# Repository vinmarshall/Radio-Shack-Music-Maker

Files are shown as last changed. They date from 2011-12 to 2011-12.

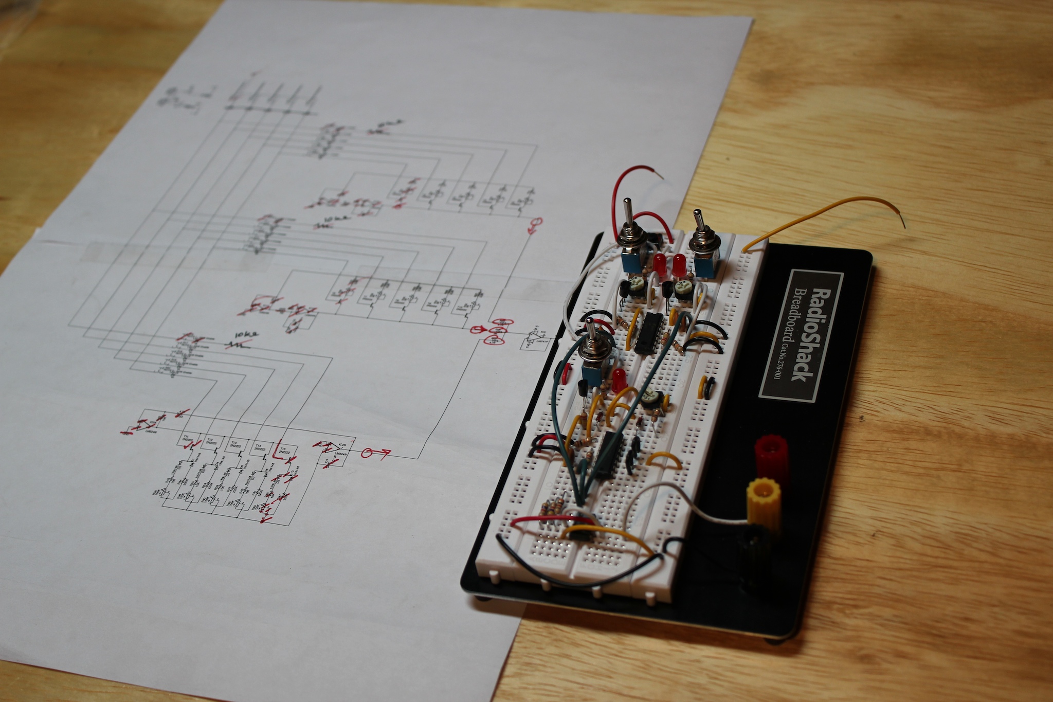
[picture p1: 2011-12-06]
images/prototype_001.jpg

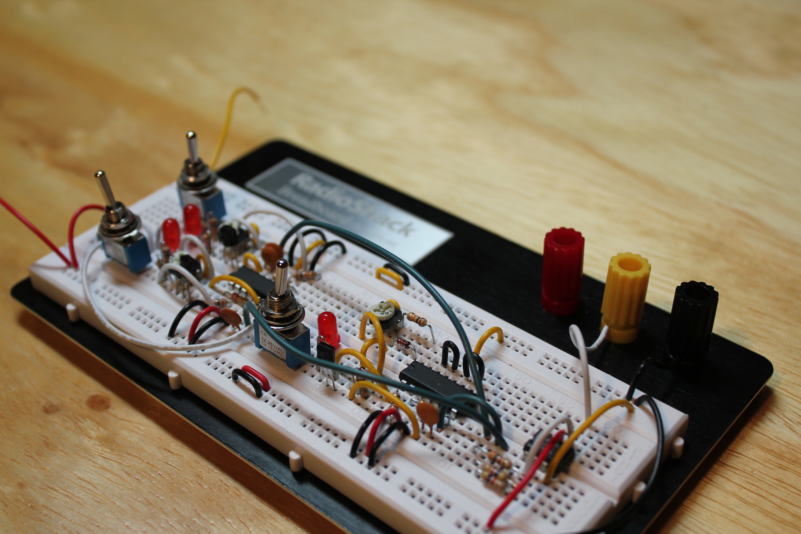
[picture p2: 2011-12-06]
images/prototype_003.jpg

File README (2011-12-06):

These files are the plans for the "Radio Shack Music Maker" in my post on PopSci:

http://www.popsci.com/diy/article/2011-11/sponsored-post-radioshack-music-maker-diy-project

./CAD The Alibre 3D model for the enclosure.

./PCB The Express PCB files - schematic and board layout.

./images Just what you'd expect.

./parts Information for sourcing parts.

./schematic The schematic.

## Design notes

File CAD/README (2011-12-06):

These files make up the 3-D model of the Music Maker.  They were made with 
Alibre CAD.  Get a copy of the software for yourself if you'd like to 
customize this enclosure or design your own.  http://www.alibre.com.

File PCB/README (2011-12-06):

These files are the schematic and PCB layout for the Music Maker.  This 
was made with the software from http://www.expresspcb.com.

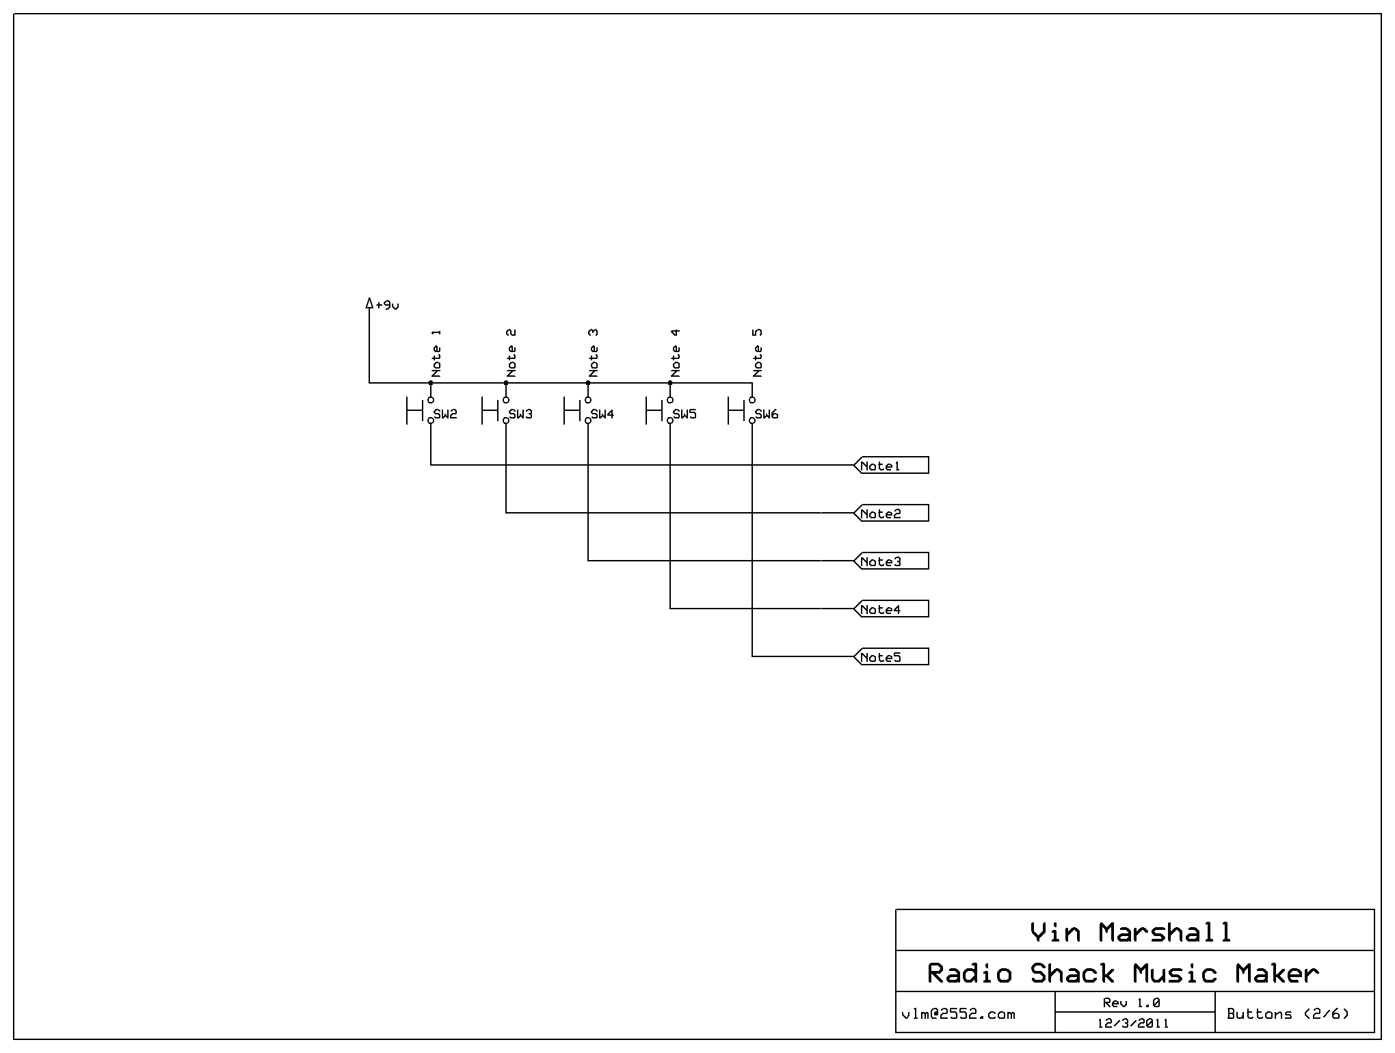
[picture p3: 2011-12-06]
schematic/2_buttons.bmp

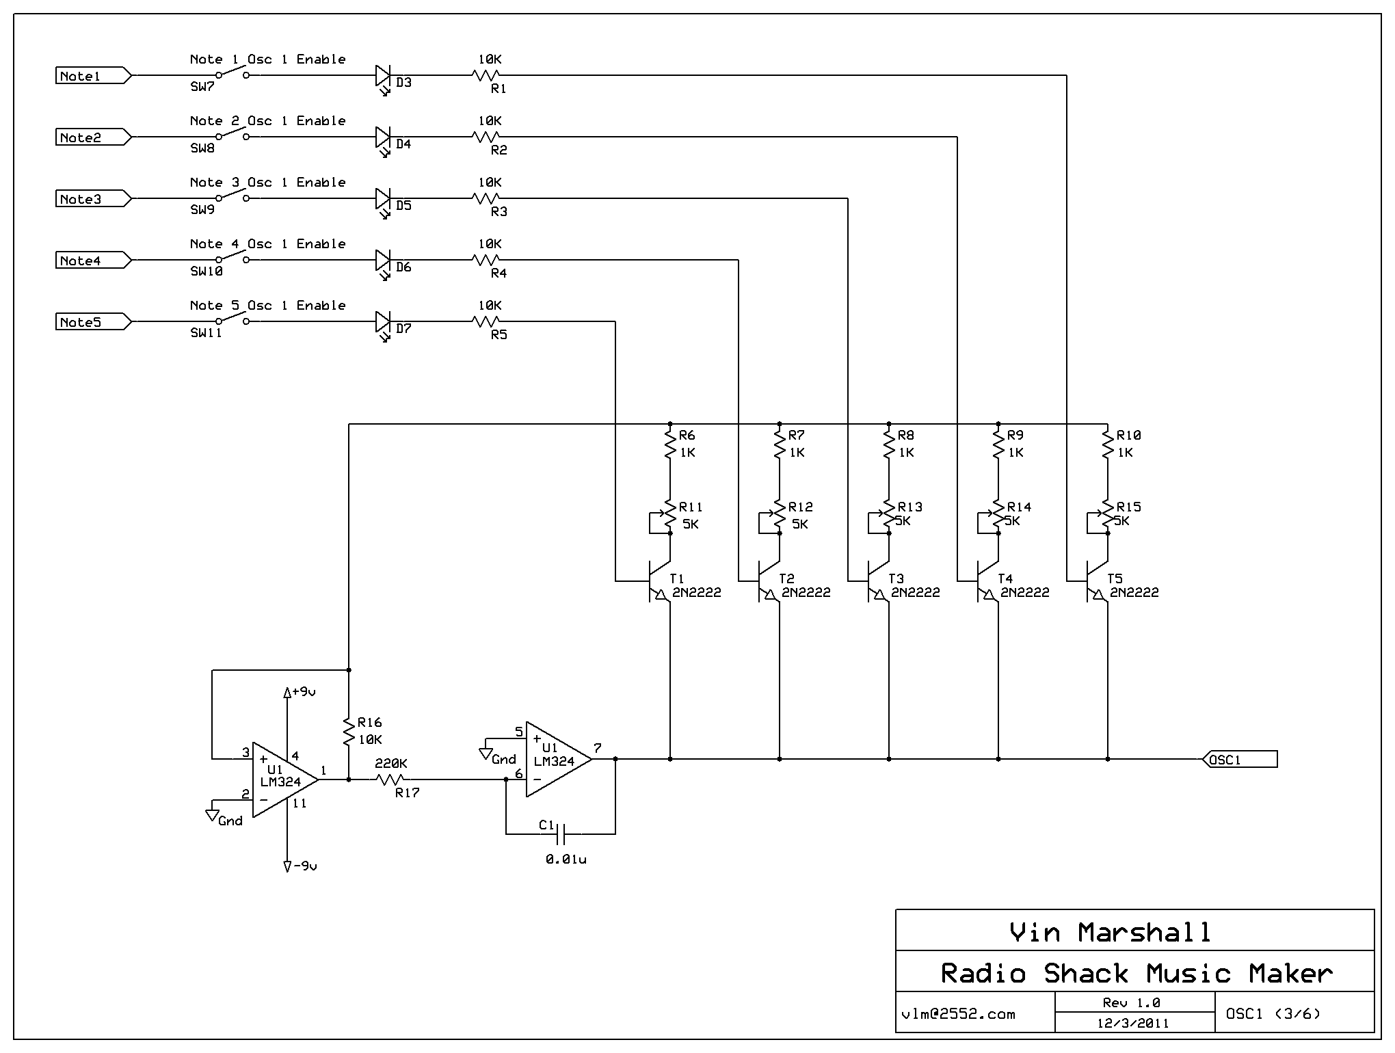
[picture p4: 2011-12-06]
schematic/3_oscillator_1.bmp

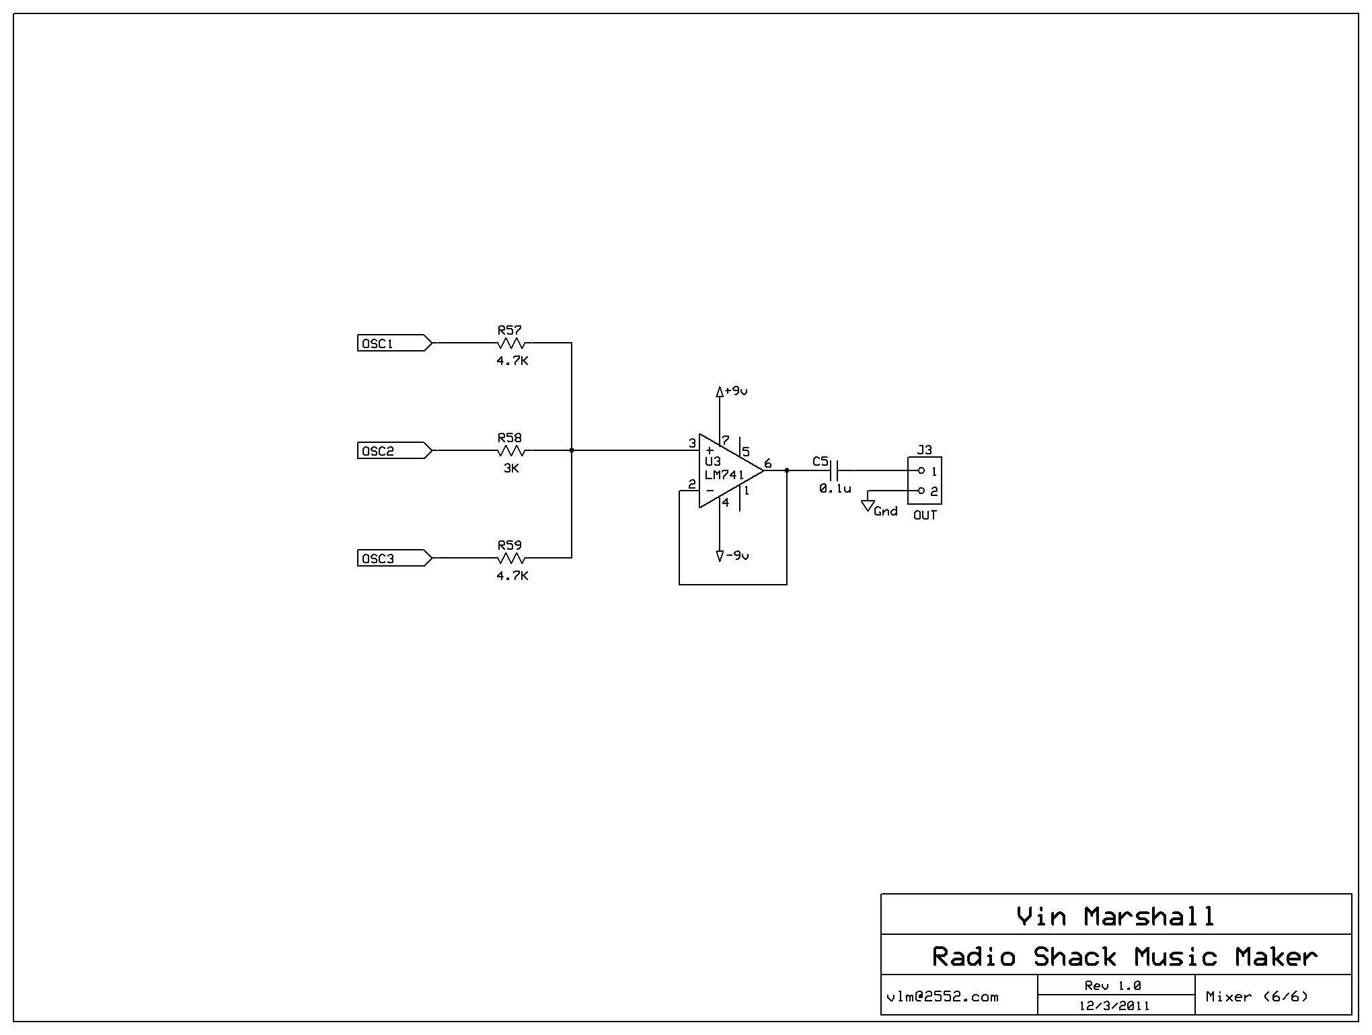
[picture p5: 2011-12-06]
schematic/6_mixer.bmp

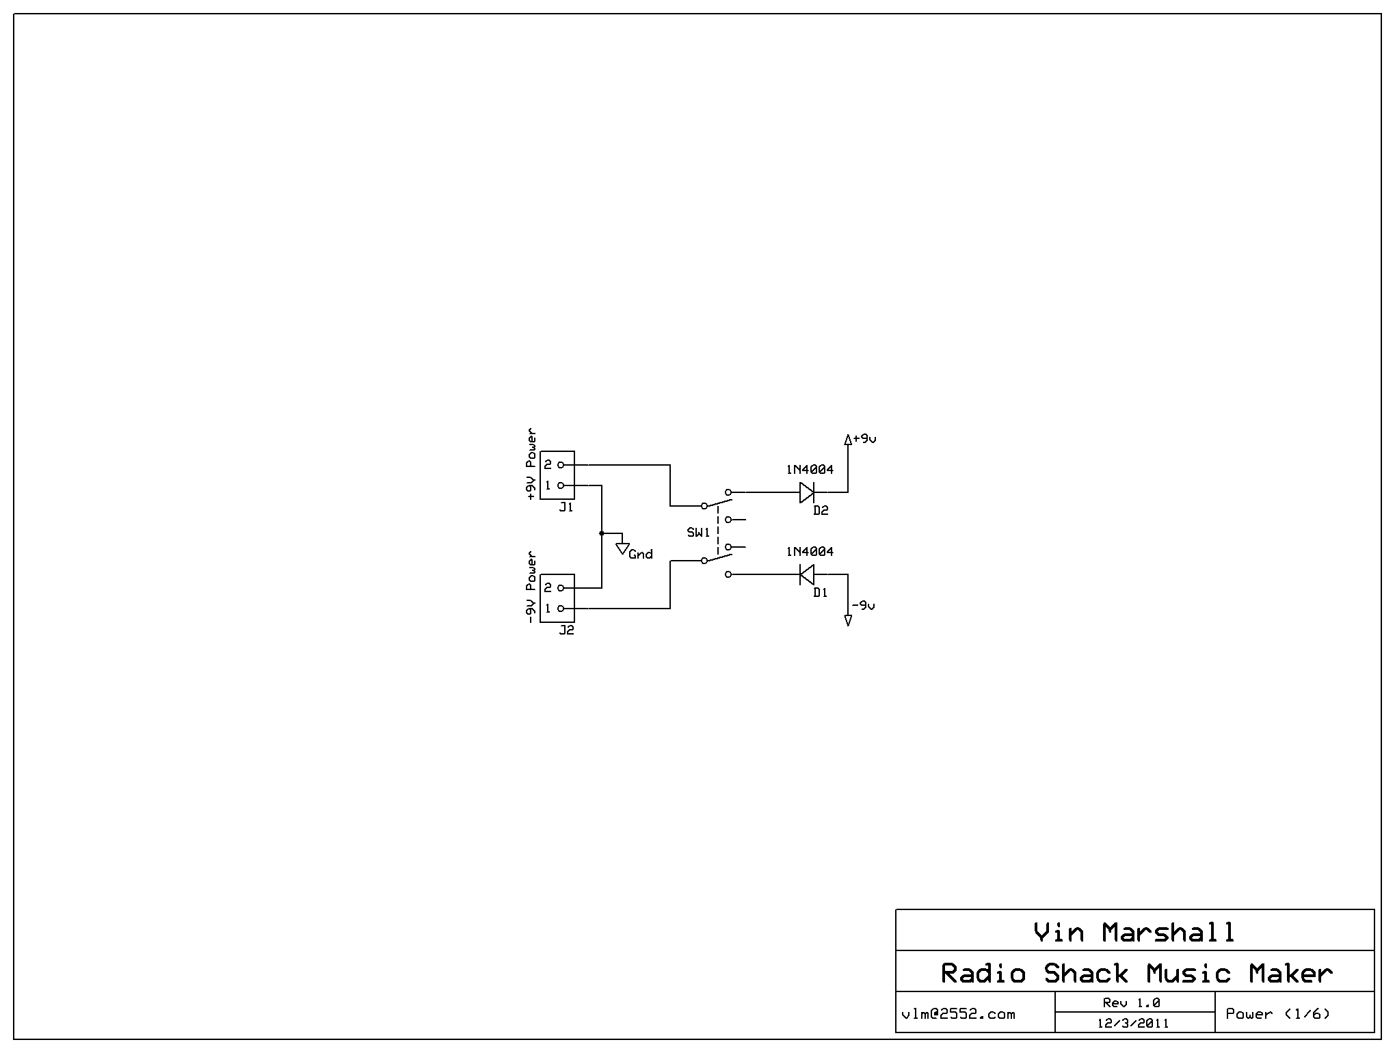
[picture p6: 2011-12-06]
schematic/1_power.bmp

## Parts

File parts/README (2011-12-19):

PCB:

The PCB can be sourced from ExpressPCB.  

The "ProtoPro" service gives you a 2 sided board with soldermask and 
silkscreening.  4 boards will cost just under $200.  

The "Standard" service gives you a perfectly functional 2 sided board with no 
soldermasks or silkscreening.  2 boards will cost about $100.

If I get sufficient interest, I'll make boards available for $40 each.

Instructions: 

- Download their software from http://www.expresspcb.com/ if you don't already 
have it.
- Open the ./PCB/music_maker.pcb file
- From the 'Layout' menu, select "Compute Board Cost" to see your options
  and then "Order Boards via the Internet" to order.

ENCLOSURE:

The front and back panels of the acrylic enclosure can be sourced from Pololu. 
It should cost around $40.

Instructions:

- Go to http://www.pololu.com/catalog/product/749 and click "Request a Quote"
- Upload the ./parts/music_maker_panels.dxf file, fill in a quantity and
  any special instructions, select a material, and wait for them to email you 
  a quote.  You can place the order at that point.

PARTS: 

I'm still working on the parts lists.

The electronics are listed in the Radio_Shack_BOM.pdf file. 

Source the standoffs and hardware from your favorite vendor.
 - 4x 2" x 0.25" OD Round standoffs, female-female, 8-32
 - 4x 3/8" x 0.25" OD Hex standoffs, female-male, 6-32
 - 4x 6-32 machine screws
 - 4x 6-32 nuts
 - 8x 8-32 machine screws
 - 2x 4-40 machine screws
 - 2x 4-40 nuts

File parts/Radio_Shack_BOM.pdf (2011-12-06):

Radio Shack Music Maker
Parts List

Push Button Switches – 5x p/n 275-609
SPST Mini Toggle Switches – 15x p/n 275-634
5K Potentiometers (cut shaft to length) – 10x p/n 271-1714 100K Potentiometers (cut shaft to length) – 5x p/n 271-092 Knobs – 4x p/n 274-415
DPDT Mini Toggle Switch – 1x p/n 275-636
1/4” Audio Jack – 1x p/n 274-252

9V Batteries – 2x p/n 23-853
9V Battery Holders – 1x p/n 270-326
9V Battery Clips – 1x p/n 270-324

1N4001 Rectifier Diodes – 1x p/n 276-1101 1N4148 Signal Diodes – 1x p/n 276-1122 Resistor Assortment – 1x p/n 271-312
LED Assortment – 2x p/n 276-1622
LM324 Quad Op Amp – 2x p/n 276-1711 LM741 Op Amp – 1x p/n 276-007
2N2222 NPN Transistors – 3x p/n 276-1617 0.01uF Capacitors – 2x p/n 272-1065 0.1uF Capacitor – 1x p/n 272-1069

Wire Assortment – p/n 278-1224

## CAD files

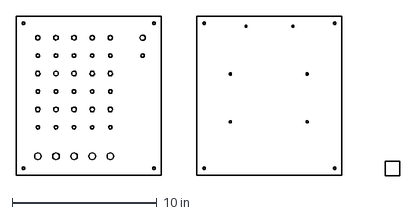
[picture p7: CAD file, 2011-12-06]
parts/music_maker_panels.dxf
26.5 x 11.0 in

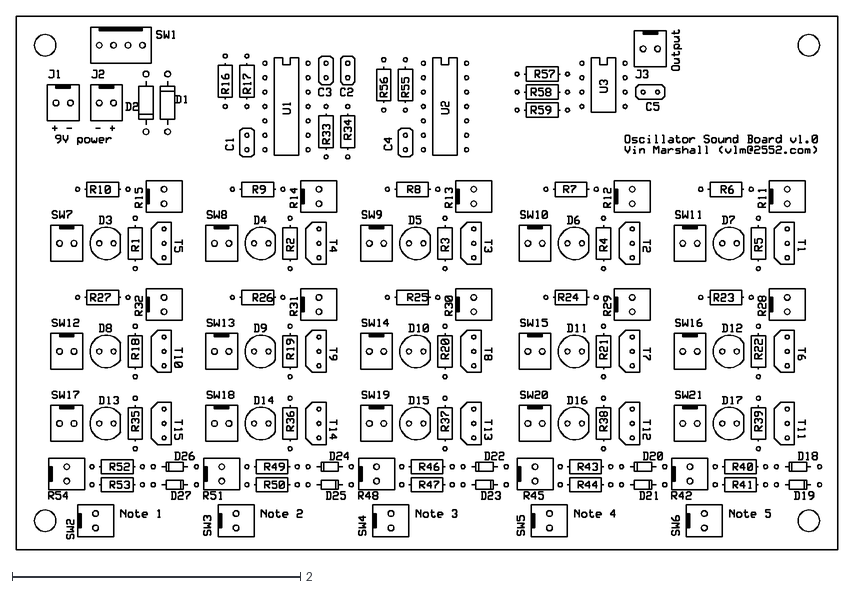
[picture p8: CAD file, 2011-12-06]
PCB/music_maker_pcb.dxf
5.70 x 3.70

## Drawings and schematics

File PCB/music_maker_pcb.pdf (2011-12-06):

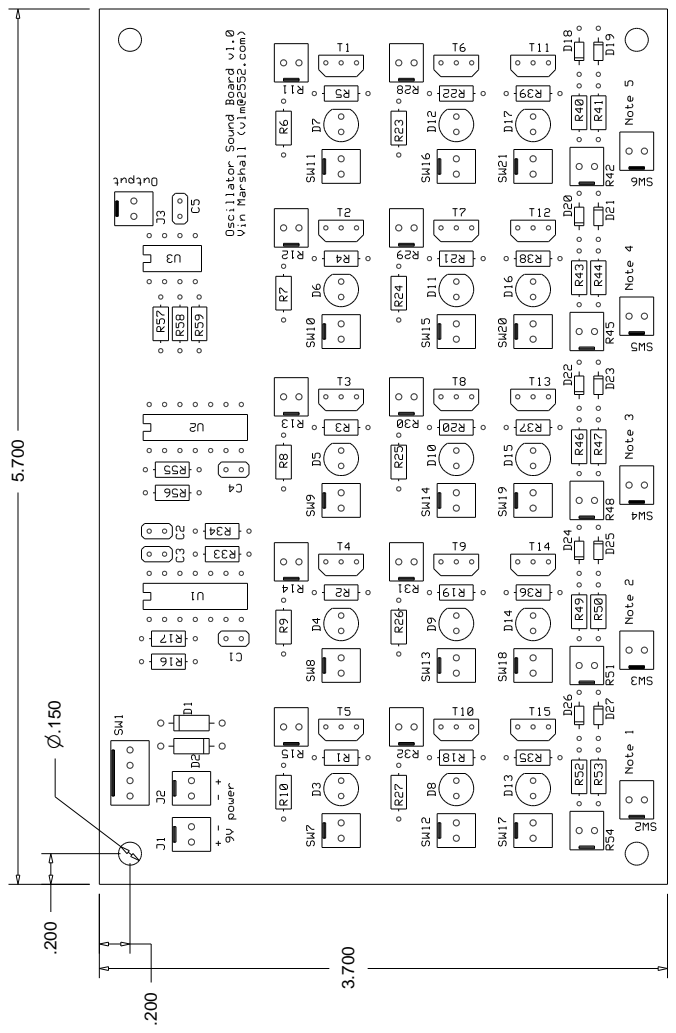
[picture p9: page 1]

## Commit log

2011-12-06 Initial commit.
    [music_maker.sch, music_maker_panels.dxf, music_maker_pcb.dxf]
2011-12-06 renamed schematic files to reflect order
